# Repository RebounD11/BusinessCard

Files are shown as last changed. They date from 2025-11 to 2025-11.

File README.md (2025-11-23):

# Overview

This is a simple 4-layer PCB, the size of a credit card (approximately - 85.6 mm x 54 mm with rounded corners) that has the main purpose of being a business card and secondary purposes of not beoming e-waste once the novelty has worn off.  

# Functionality

## First impression 

When handing out the card, the front side will look like this:

## Power up

## Connecting

## Clearing connections

## Clock functionality

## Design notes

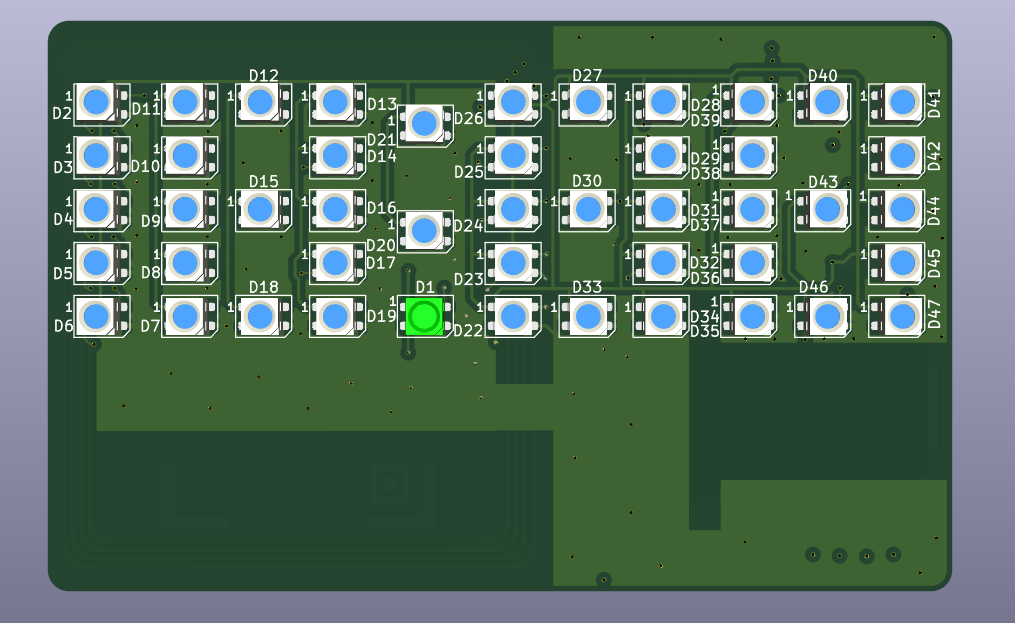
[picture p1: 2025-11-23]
Images/Config_PM_Indicator.png

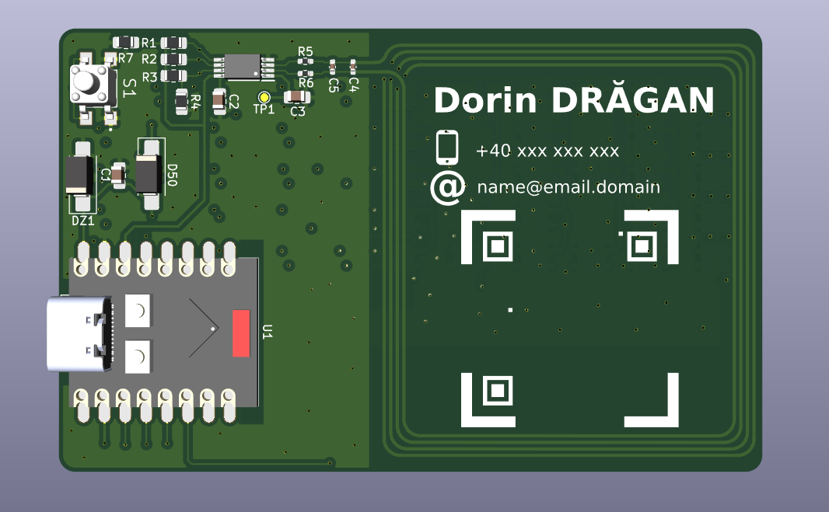
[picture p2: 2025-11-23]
Images/Front.png

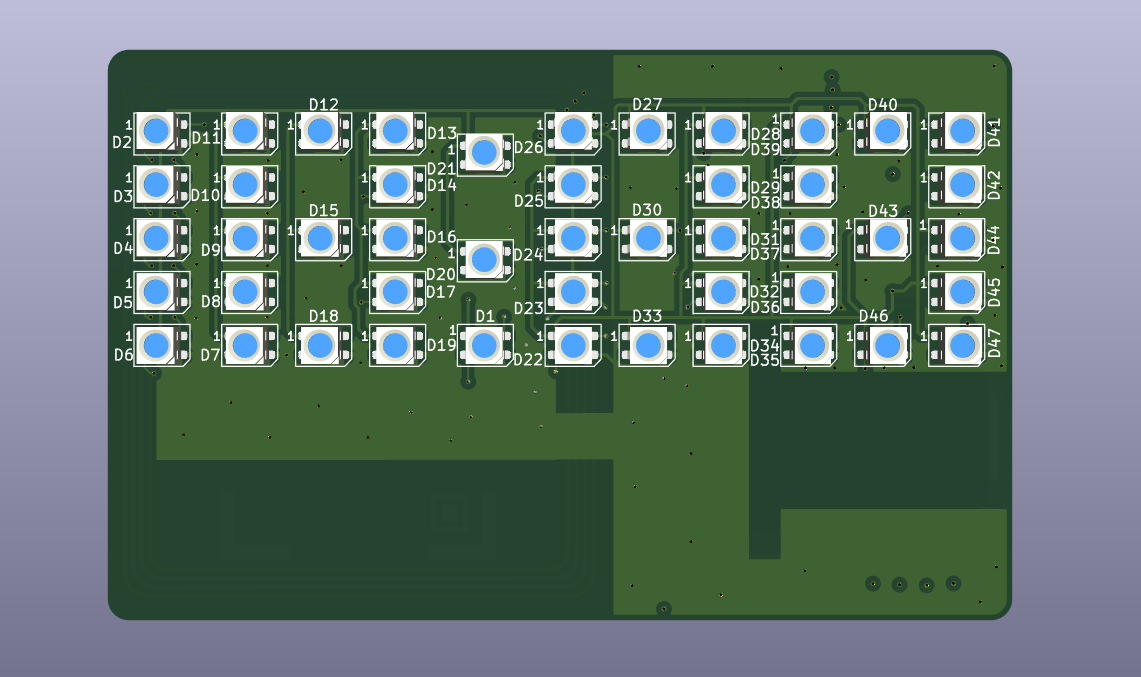
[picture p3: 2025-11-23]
Images/Clock.png

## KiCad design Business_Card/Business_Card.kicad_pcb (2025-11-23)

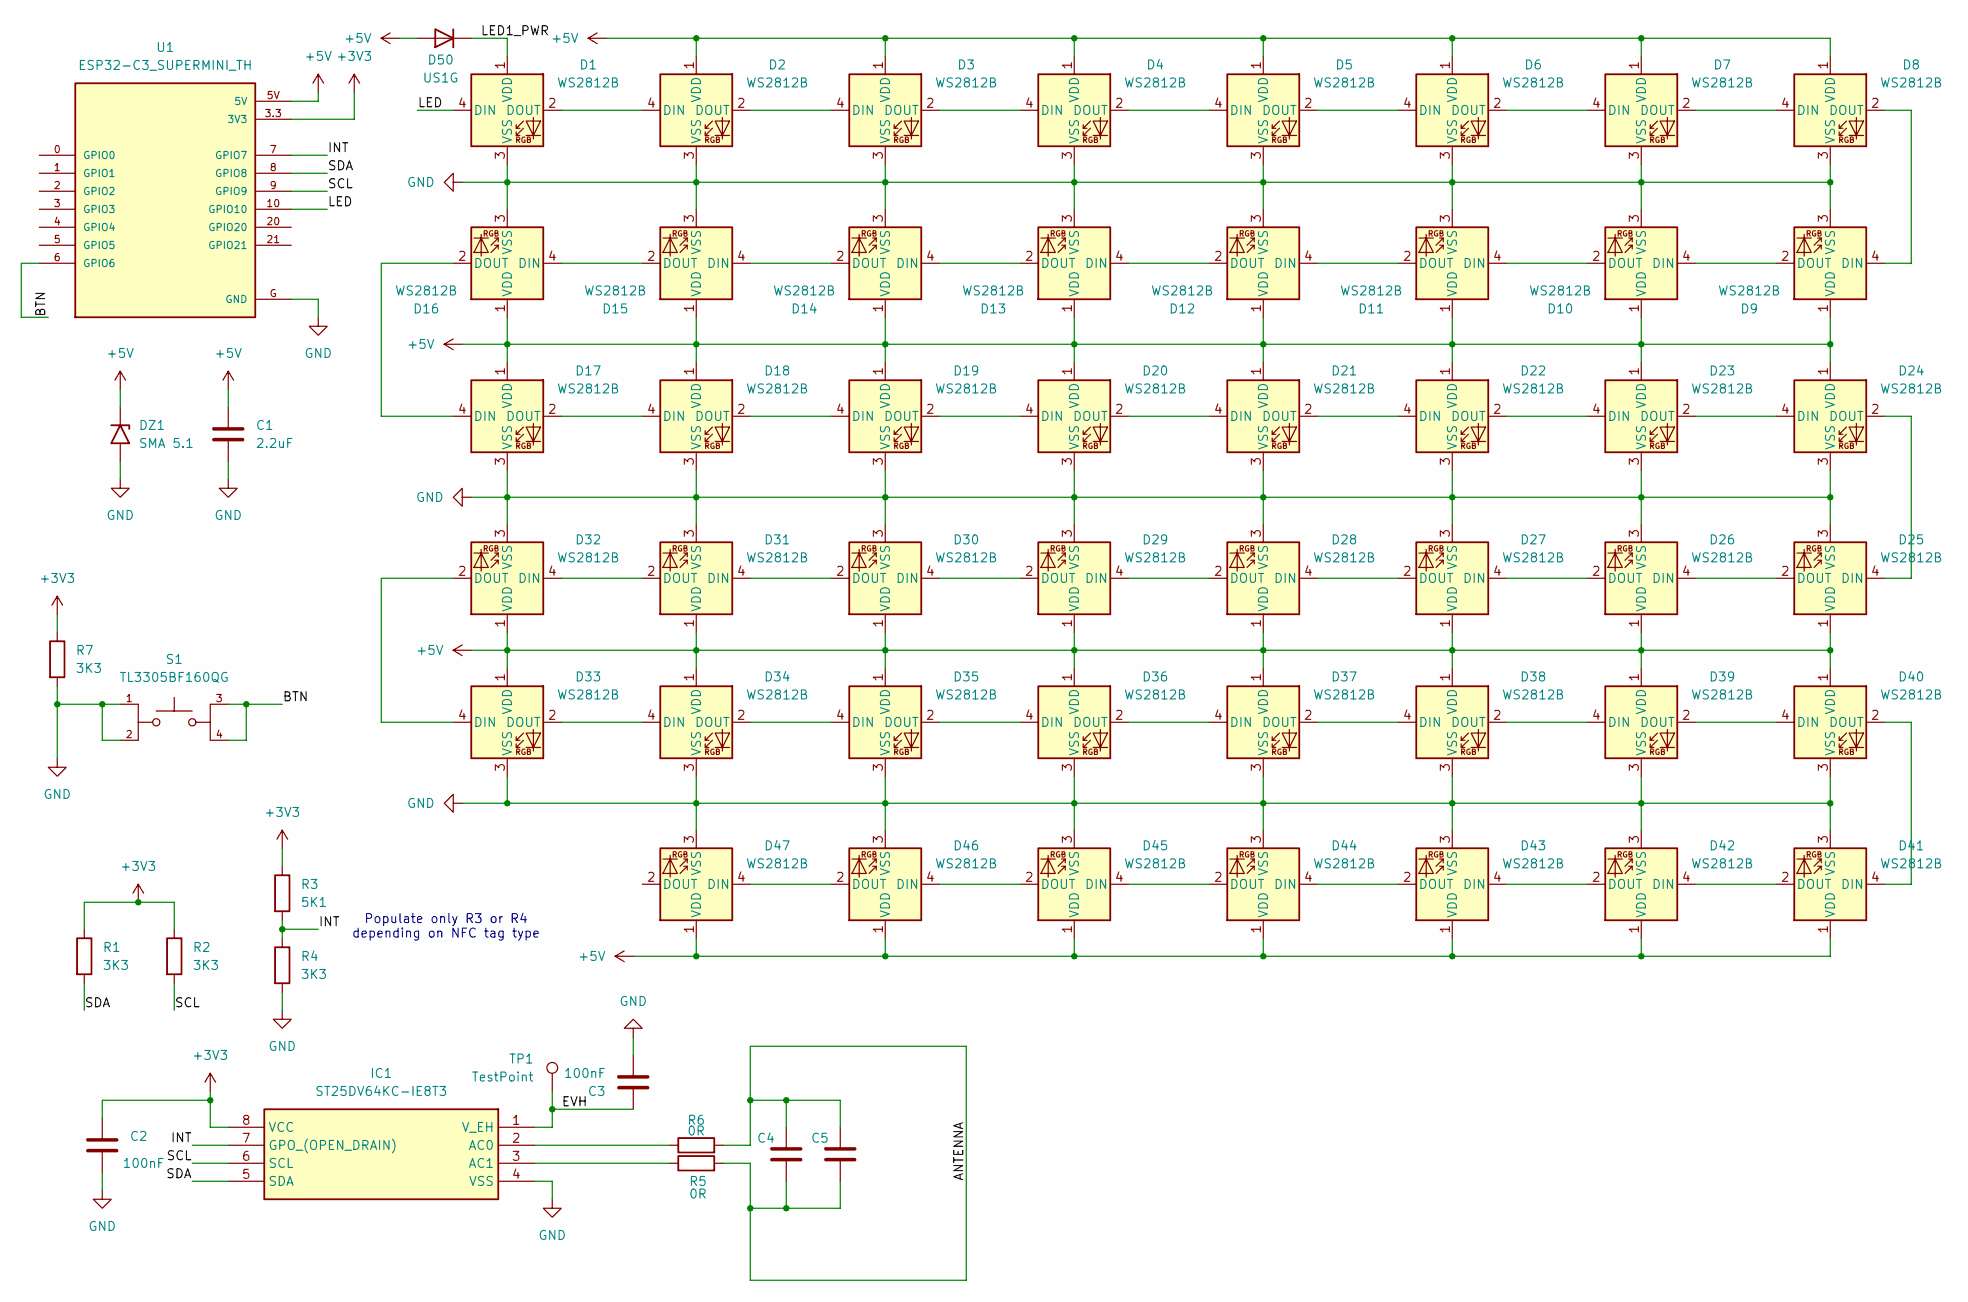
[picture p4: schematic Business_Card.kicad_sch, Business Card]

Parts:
C1: 2.2uF; C_0805_2012Metric_Pad1.18x1.45mm_HandSolder
C2, C3: 100nF; C_0805_2012Metric_Pad1.18x1.45mm_HandSolder
C4, C5: C_0402_1005Metric_Pad0.74x0.62mm_HandSolder
D1, D2, D3, D4, D5, D6, D7, D8, D9, D10, D11, D12, D13, D14, D15, D16, D17, D18, D19, D20, D21, D22, D23, D24, D25, D26, D27, D28, D29, D30, D31, D32, D33, D34, D35, D36, D37, D38, D39, D40, D41, D42, D43, D44, D45, D46, D47: WS2812B; LED_WS2812B-Mini_PLCC4_3.5x3.5mm
D50: US1G; D_SMA_Handsoldering
DZ1: SMA 5.1; D_SMA_Handsoldering
IC1: ST25DV64KC-IE8T3; SOP65P640X120-8N; Mouser Part Number 511-ST25DV64KC-IE8T3
R1, R2, R4, R7: 3K3; R_0805_2012Metric_Pad1.20x1.40mm_HandSolder
R3: 5K1; R_0805_2012Metric_Pad1.20x1.40mm_HandSolder
R5, R6: 0R; R_0402_1005Metric_Pad0.72x0.64mm_HandSolder
S1: TL3305BF160QG; SW_TL3305BF160QG; PARTREV C
TP1: TestPoint; TestPoint_Pad_D1.0mm
U1: ESP32-C3_SUPERMINI_TH; MODULE_ESP32-C3_SUPERMINI_TH

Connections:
+3V3: C2.1, IC1.8 (VCC), R1.1, R2.1, R3.1, R7.1, U1.3.3 (3V3)
+5V: C1.1, D2.1 (VDD), D3.1 (VDD), D4.1 (VDD), D5.1 (VDD), D6.1 (VDD), D7.1 (VDD), D8.1 (VDD), D9.1 (VDD), D10.1 (VDD), D11.1 (VDD), D12.1 (VDD), D13.1 (VDD), D14.1 (VDD), D15.1 (VDD), D16.1 (VDD), D17.1 (VDD), D18.1 (VDD), D19.1 (VDD), D20.1 (VDD), D21.1 (VDD), D22.1 (VDD), D23.1 (VDD), D24.1 (VDD), D25.1 (VDD), D26.1 (VDD), D27.1 (VDD), D28.1 (VDD), D29.1 (VDD), D30.1 (VDD), D31.1 (VDD), D32.1 (VDD), D33.1 (VDD), D34.1 (VDD), D35.1 (VDD), D36.1 (VDD), D37.1 (VDD), D38.1 (VDD), D39.1 (VDD), D40.1 (VDD), D41.1 (VDD), D42.1 (VDD), D43.1 (VDD), D44.1 (VDD), D45.1 (VDD), D46.1 (VDD), D47.1 (VDD), D50.2 (A), DZ1.1 (A1), U1.5V
/ANTENNA: C4.1, C4.2, C5.1, C5.2, R5.2, R6.2
/BTN: S1.3, S1.4, U1.6 (GPIO6)
/EVH: C3.1, IC1.1 (V_EH), TP1.1
/INT: IC1.7 (GPO_(OPEN_DRAIN)), R3.2, R4.1, U1.7 (GPIO7)
/LED: D1.4 (DIN), U1.10 (GPIO10)
/LED1_PWR: D1.1 (VDD), D50.1 (K)
/SCL: IC1.6 (SCL), R2.2, U1.9 (GPIO9)
/SDA: IC1.5 (SDA), R1.2, U1.8 (GPIO8)
GND: C1.2, C2.2, C3.2, D1.3 (VSS), D2.3 (VSS), D3.3 (VSS), D4.3 (VSS), D5.3 (VSS), D6.3 (VSS), D7.3 (VSS), D8.3 (VSS), D9.3 (VSS), D10.3 (VSS), D11.3 (VSS), D12.3 (VSS), D13.3 (VSS), D14.3 (VSS), D15.3 (VSS), D16.3 (VSS), D17.3 (VSS), D18.3 (VSS), D19.3 (VSS), D20.3 (VSS), D21.3 (VSS), D22.3 (VSS), D23.3 (VSS), D24.3 (VSS), D25.3 (VSS), D26.3 (VSS), D27.3 (VSS), D28.3 (VSS), D29.3 (VSS), D30.3 (VSS), D31.3 (VSS), D32.3 (VSS), D33.3 (VSS), D34.3 (VSS), D35.3 (VSS), D36.3 (VSS), D37.3 (VSS), D38.3 (VSS), D39.3 (VSS), D40.3 (VSS), D41.3 (VSS), D42.3 (VSS), D43.3 (VSS), D44.3 (VSS), D45.3 (VSS), D46.3 (VSS), D47.3 (VSS), DZ1.2 (A2), IC1.4 (VSS), R4.2, R7.2, S1.1, S1.2, U1.G (GND)
unnamed: D1.2 (DOUT), D2.4 (DIN)
unnamed: D2.2 (DOUT), D3.4 (DIN)
unnamed: D3.2 (DOUT), D4.4 (DIN)
unnamed: D4.2 (DOUT), D5.4 (DIN)
unnamed: D5.2 (DOUT), D6.4 (DIN)
unnamed: D6.2 (DOUT), D7.4 (DIN)
unnamed: D7.2 (DOUT), D8.4 (DIN)
unnamed: D8.2 (DOUT), D9.4 (DIN)
unnamed: D9.2 (DOUT), D10.4 (DIN)
unnamed: D10.2 (DOUT), D11.4 (DIN)
unnamed: D11.2 (DOUT), D12.4 (DIN)
unnamed: D12.2 (DOUT), D13.4 (DIN)
unnamed: D13.2 (DOUT), D14.4 (DIN)
unnamed: D14.2 (DOUT), D15.4 (DIN)
unnamed: D15.2 (DOUT), D16.4 (DIN)
unnamed: D16.2 (DOUT), D17.4 (DIN)
unnamed: D17.2 (DOUT), D18.4 (DIN)
unnamed: D18.2 (DOUT), D19.4 (DIN)
unnamed: D19.2 (DOUT), D20.4 (DIN)
unnamed: D20.2 (DOUT), D21.4 (DIN)
unnamed: D21.2 (DOUT), D22.4 (DIN)
unnamed: D22.2 (DOUT), D23.4 (DIN)
unnamed: D23.2 (DOUT), D24.4 (DIN)
unnamed: D24.2 (DOUT), D25.4 (DIN)
unnamed: D25.2 (DOUT), D26.4 (DIN)
unnamed: D26.2 (DOUT), D27.4 (DIN)
unnamed: D27.2 (DOUT), D28.4 (DIN)
unnamed: D28.2 (DOUT), D29.4 (DIN)
unnamed: D29.2 (DOUT), D30.4 (DIN)
unnamed: D30.2 (DOUT), D31.4 (DIN)
unnamed: D31.2 (DOUT), D32.4 (DIN)
unnamed: D32.2 (DOUT), D33.4 (DIN)
unnamed: D33.2 (DOUT), D34.4 (DIN)
unnamed: D34.2 (DOUT), D35.4 (DIN)
unnamed: D35.2 (DOUT), D36.4 (DIN)
unnamed: D36.2 (DOUT), D37.4 (DIN)
unnamed: D37.2 (DOUT), D38.4 (DIN)
unnamed: D38.2 (DOUT), D39.4 (DIN)
unnamed: D39.2 (DOUT), D40.4 (DIN)
unnamed: D40.2 (DOUT), D41.4 (DIN)
unnamed: D41.2 (DOUT), D42.4 (DIN)
unnamed: D42.2 (DOUT), D43.4 (DIN)
unnamed: D43.2 (DOUT), D44.4 (DIN)
unnamed: D44.2 (DOUT), D45.4 (DIN)
unnamed: D45.2 (DOUT), D46.4 (DIN)
unnamed: D46.2 (DOUT), D47.4 (DIN)
unnamed: IC1.2 (AC0), R6.1
unnamed: IC1.3 (AC1), R5.1

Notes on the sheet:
Populate only R3 or R4 depending on NFC tag type

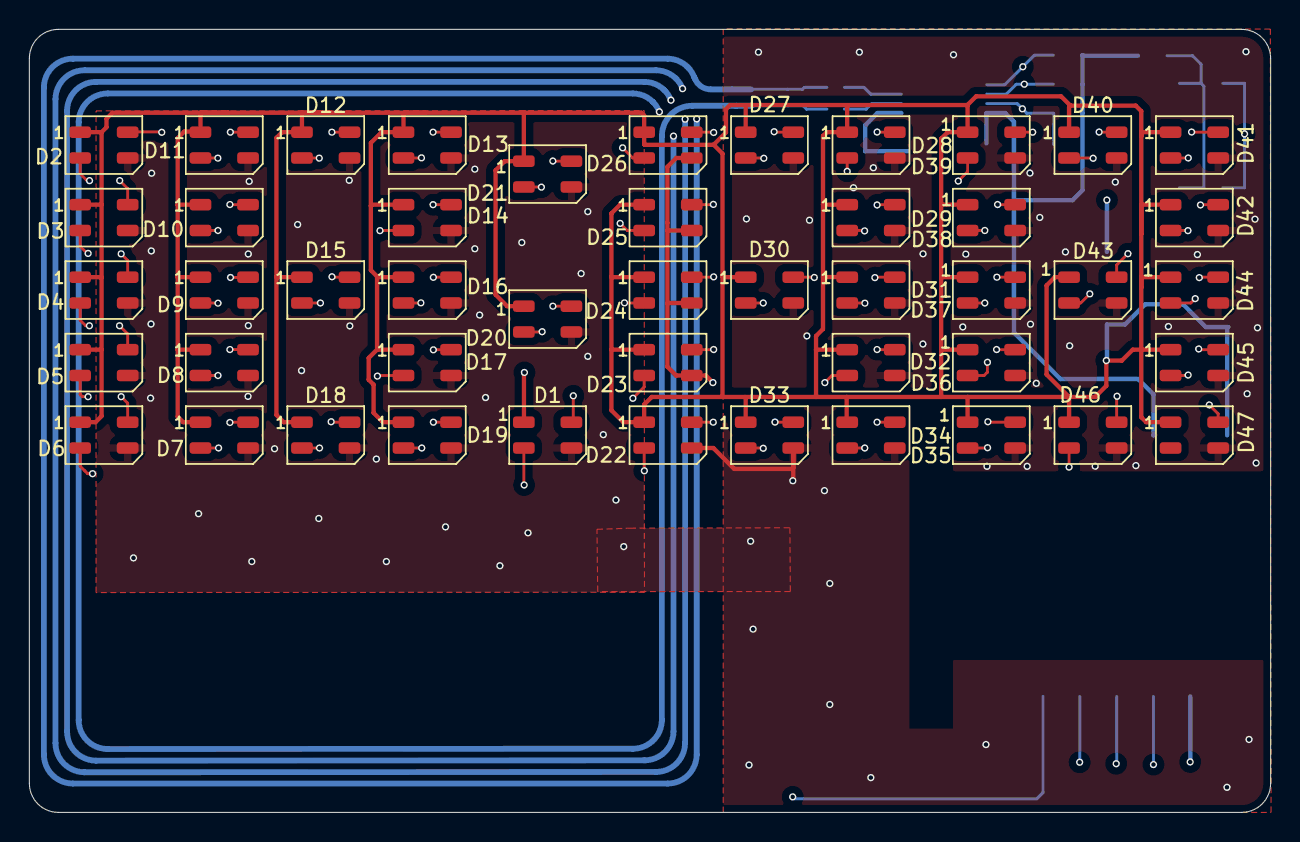
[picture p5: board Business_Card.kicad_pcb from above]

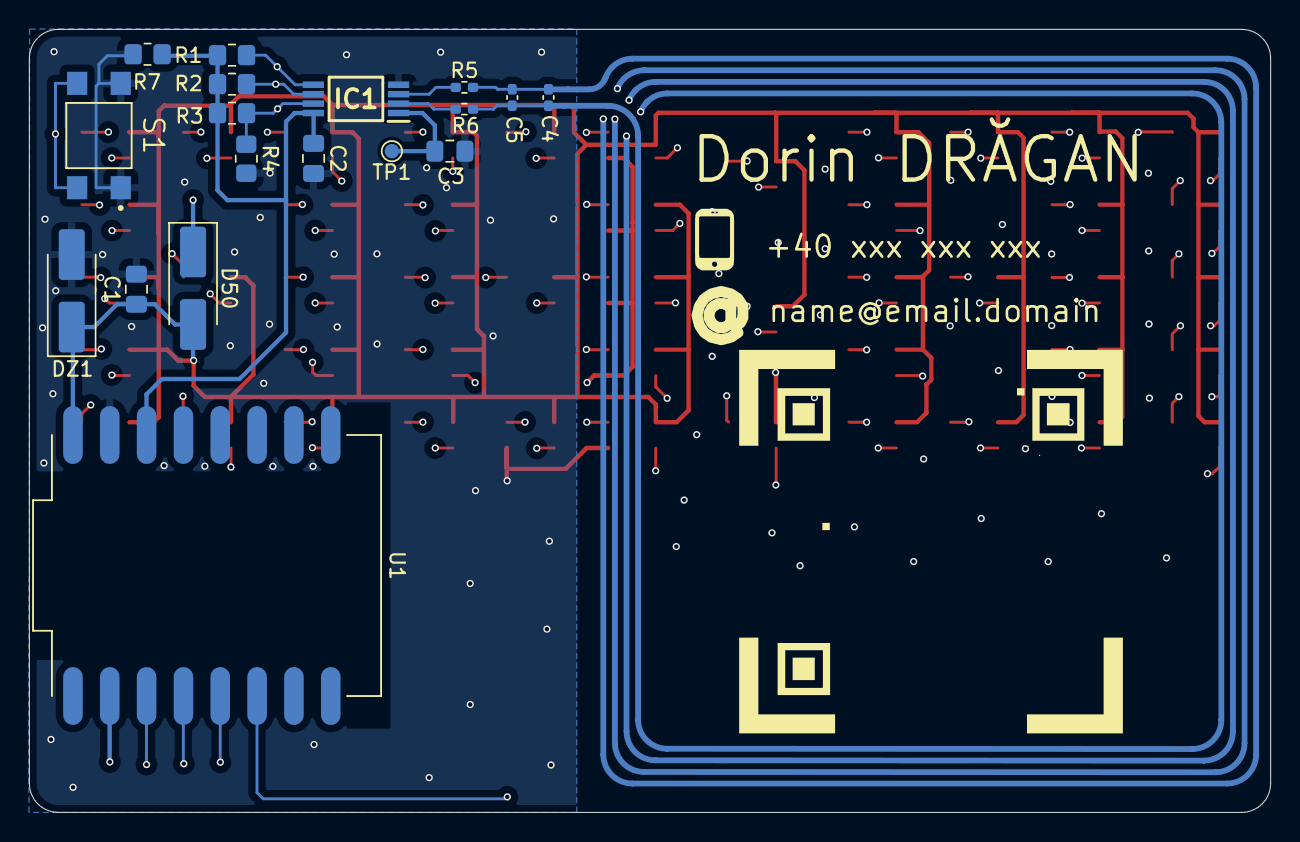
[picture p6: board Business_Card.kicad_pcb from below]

Board: 4 copper layers, 85.6 x 54.0 mm, 65 parts (18 on the bottom side), 59 nets.

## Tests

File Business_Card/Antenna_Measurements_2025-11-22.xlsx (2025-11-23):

 |  |  |  |  | R_A = R_SDC+R_SAC
 |  |  |  |  | L_A = L_A @1 MHz
 |  |  |  |  | C_A = 1/(L_A*(2πF_res)^2)
 |  |  |  |  |  |  |  |  | VNA
Markers [MHz] |  | L_A [µH] | R_SDC [Ω] | R_PAC [kΩ] | R_SAC [Ω] | Q | C_A [pF] | R_A [Ω] | L_A [nH] | C_A [pF] | R_A [Ω]
1 |  | 1.872 | 1.41 |  |  |  |  |  | 1872 | 31.63977235 | 4.440596464
13.56 |  | 3.117 |  | 8.393878766 | 3.030596464 | 35.91733402 |  | 4.440596464
F_res | 20.68 |  |  | 6.797 |  |  | 31.63977235

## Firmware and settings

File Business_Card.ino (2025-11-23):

// Business card
#include <Adafruit_NeoPixel.h>
#include <WiFiManager.h>
#include "time.h"

#define LED_PIN 10
#define BUTTON_PIN 6

#define LED_COUNT 47

Adafruit_NeoPixel strip(LED_COUNT, LED_PIN, NEO_GRB + NEO_KHZ800);
WiFiManager wm;

const char* ntpServer = "0.ro.pool.ntp.org";
const long  gmtOffset_sec = 7200;
int   daylightOffset_sec = 3600;
bool secOn = false;
volatile bool btnPush = false;
volatile int cntPush = 0;
//variables to keep track of the timing of recent interrupts
volatile unsigned long button_time = 0;
volatile unsigned long last_button_time = 0;

uint32_t color;
struct tm timeinfo;

void IRAM_ATTR buttonPressed() {
  button_time = millis();
  if (button_time - last_button_time > 250) {
    if (cntPush == 6) {
      cntPush = 0;
    }
    else {
      cntPush++;
    }
    btnPush = true;
    last_button_time = button_time;
  }
}

void setup() {
  // put your setup code here, to run once:
  // initialize strip
  strip.begin();           // INITIALIZE NeoPixel strip object (REQUIRED)
  strip.show();            // Turn OFF all pixels ASAP
  strip.setBrightness(50); // Set BRIGHTNESS to about 1/5 (max = 255)
  strip.setPixelColor(0, strip.Color(255,  127,  63));
  strip.show();
  // initialize button
  pinMode(BUTTON_PIN, INPUT_PULLUP);
  // initialize WiFi
  WiFi.mode(WIFI_STA); // explicitly set mode, esp defaults to STA+AP 
  // initalize WiFi Manager
  std::vector<const char *> menu = {"wifi","info","param","sep","restart","exit"};
  wm.setMenu(menu);
  wm.setClass("invert"); // dark mode
  wm.setConnectTimeout(120);
  wm.setConfigPortalTimeout(120);
  bool res;
  if (digitalRead(BUTTON_PIN) == LOW) {
    delay(3000);
    if (digitalRead(BUTTON_PIN) == LOW) {
      wm.resetSettings();
      ESP.restart();
    }
    wm.setConfigPortalTimeout(120);
    if (!wm.startConfigPortal("OnDemandAP","password")) {
      delay(3000);
      //ESP.restart();
    } else {
      //if you get here you have connected to the WiFi
      // get NTP time
      configTime(gmtOffset_sec, daylightOffset_sec, ntpServer);
    }
  }
  else {
    res = wm.autoConnect("AutoConnectAP","password");
    if (!res) {
      //ESP.restart();
    }
    else {
      //if you get here you have connected to the WiFi
      // get NTP time
      configTime(gmtOffset_sec, daylightOffset_sec, ntpServer);
    }
  }
  attachInterrupt(BUTTON_PIN, buttonPressed, FALLING);
}

void loop() {
  // put your main code here, to run repeatedly:
  // check if button was pressed
  if (btnPush) {
    // set color
    switch (cntPush) {
      case 0:
        color = strip.Color(127, 127, 127);
        break;
      case 1:
        color = strip.Color(127, 0, 0);
        break;
      case 2:
        color = strip.Color(0, 127, 0);
        break;
      case 3:
        color = strip.Color(0, 0, 127);
        break;
      case 4:
        color = strip.Color(127, 127, 0);
        break;
      case 5:
        color = strip.Color(127, 0, 127);
        break;
      case 6:
        color = strip.Color(0, 127, 127);
        break;
      default:
        //default to white
        color = strip.Color(127, 127, 127);
        break;
    }
    btnPush = false;
  }
  // actual app
  if(!getLocalTime(&timeinfo)){
    // failed to get time
  }
  else {
    // clear clock
    for (int i=0; i<LED_COUNT; i++) {
      strip.setPixelColor(i, strip.Color(0, 0, 0));
    }
    secOn = !secOn;
    // set PM indicator
    if (timeinfo.tm_hour >= 12) {
      strip.setPixelColor(0, color);
    }
    else {
      strip.setPixelColor(0, strip.Color(0, 0, 0));
    }
    // hour tens - 1 or none
    if ((timeinfo.tm_hour == 0) || (timeinfo.tm_hour == 10) || (timeinfo.tm_hour == 11) || (timeinfo.tm_hour == 12) || (timeinfo.tm_hour == 22) || (timeinfo.tm_hour == 23)) {
      for (int i=1; i<=5; i++) {
        strip.setPixelColor(i, color);
      }
    }
    else {
      for (int i=1; i<=5; i++) {
        strip.setPixelColor(i, strip.Color(0, 0, 0));
      }
    }
    // hour units - 0
    if ((timeinfo.tm_hour == 22) || (timeinfo.tm_hour == 10)) {
      strip.setPixelColor(6, color);
      strip.setPixelColor(7, color);
      strip.setPixelColor(8, color);
      strip.setPixelColor(9, color);
      strip.setPixelColor(10, color);
      strip.setPixelColor(11, color);
      strip.setPixelColor(12, color);
      strip.setPixelColor(13, color);
      strip.setPixelColor(15, color);
      strip.setPixelColor(16, color);
      strip.setPixelColor(17, color);
      strip.setPixelColor(18, color);
    }
    // hour units - 1
    else if ((timeinfo.tm_hour == 23) || (timeinfo.tm_hour == 11) || (timeinfo.tm_hour == 13) || (timeinfo.tm_hour == 1)) {
      strip.setPixelColor(12, color);
      strip.setPixelColor(13, color);
      strip.setPixelColor(15, color);
      strip.setPixelColor(16, color);
      strip.setPixelColor(18, color);
    }
    // hour units - 2
    else if ((timeinfo.tm_hour == 0) || (timeinfo.tm_hour == 12) || (timeinfo.tm_hour == 14) || (timeinfo.tm_hour == 2)) {
      strip.setPixelColor(6, color);
      strip.setPixelColor(7, color);
      strip.setPixelColor(8, color);
      strip.setPixelColor(10, color);
      strip.setPixelColor(11, color);
      strip.setPixelColor(12, color);
      strip.setPixelColor(13, color);
      strip.setPixelColor(14, color);
      strip.setPixelColor(15, color);
      strip.setPixelColor(17, color);
      strip.setPixelColor(18, color);
    }
    // hour units - 3
    else if ((timeinfo.tm_hour == 3) || (timeinfo.tm_hour == 15)) {
      strip.setPixelColor(6, color);
      strip.setPixelColor(8, color);
      strip.setPixelColor(10, color);
      strip.setPixelColor(11, color);
      strip.setPixelColor(12, color);
      strip.setPixelColor(13, color);
      strip.setPixelColor(14, color);
      strip.setPixelColor(15, color);
      strip.setPixelColor(16, color);
      strip.setPixelColor(17, color);
      strip.setPixelColor(18, color);
    }
    // hour units - 4
    else if ((timeinfo.tm_hour == 4) || (timeinfo.tm_hour == 16)) {
      strip.setPixelColor(8, color);
      strip.setPixelColor(9, color);
      strip.setPixelColor(10, color);
      strip.setPixelColor(12, color);
      strip.setPixelColor(13, color);
      strip.setPixelColor(14, color);
      strip.setPixelColor(15, color);
      strip.setPixelColor(16, color);
      strip.setPixelColor(18, color);
    }
    // hour units - 5
    else if ((timeinfo.tm_hour == 5) || (timeinfo.tm_hour == 17)) {
      strip.setPixelColor(6, color);
      strip.setPixelColor(8, color);
      strip.setPixelColor(9, color);
      strip.setPixelColor(10, color);
      strip.setPixelColor(11, color);
      strip.setPixelColor(12, color);
      strip.setPixelColor(14, color);
      strip.setPixelColor(15, color);
      strip.setPixelColor(16, color);
      strip.setPixelColor(17, color);
      strip.setPixelColor(18, color);
    }
    // hour units - 6
    else if ((timeinfo.tm_hour == 6) || (timeinfo.tm_hour == 18)) {
      strip.setPixelColor(6, color);
      strip.setPixelColor(7, color);
      strip.setPixelColor(8, color);
      strip.setPixelColor(9, color);
      strip.setPixelColor(10, color);
      strip.setPixelColor(11, color);
      strip.setPixelColor(12, color);
      strip.setPixelColor(14, color);
      strip.setPixelColor(15, color);
      strip.setPixelColor(16, color);
      strip.setPixelColor(17, color);
      strip.setPixelColor(18, color);
    }
    // hour units - 7
    else if ((timeinfo.tm_hour == 7) || (timeinfo.tm_hour == 19)) {
      strip.setPixelColor(10, color);
      strip.setPixelColor(11, color);
      strip.setPixelColor(12, color);
      strip.setPixelColor(13, color);
      strip.setPixelColor(15, color);
      strip.setPixelColor(16, color);
      strip.setPixelColor(18, color);
    }
    // hour units - 8
    else if ((timeinfo.tm_hour == 8) || (timeinfo.tm_hour == 20)) {
      strip.setPixelColor(6, color);
      strip.setPixelColor(7, color);
      strip.setPixelColor(8, color);
      strip.setPixelColor(9, color);
      strip.setPixelColor(10, color);
      strip.setPixelColor(11, color);
      strip.setPixelColor(12, color);
      strip.setPixelColor(13, color);
      strip.setPixelColor(14, color);
      strip.setPixelColor(15, color);
      strip.setPixelColor(16, color);
      strip.setPixelColor(17, color);
      strip.setPixelColor(18, color);
    }
    // hour units - 9
    else if ((timeinfo.tm_hour == 9) || (timeinfo.tm_hour == 21)) {
      strip.setPixelColor(6, color);
      strip.setPixelColor(8, color);
      strip.setPixelColor(9, color);
      strip.setPixelColor(10, color);
      strip.setPixelColor(11, color);
      strip.setPixelColor(12, color);
      strip.setPixelColor(13, color);
      strip.setPixelColor(14, color);
      strip.setPixelColor(15, color);
      strip.setPixelColor(16, color);
      strip.setPixelColor(17, color);
      strip.setPixelColor(18, color);
    }
    if (secOn) {
      strip.setPixelColor(19, color);
      strip.setPixelColor(20, color);
    }
    else {
      strip.setPixelColor(19, strip.Color(0, 0, 0));
      strip.setPixelColor(20, strip.Color(0, 0, 0));
    }
    // min tens is 0
    if (timeinfo.tm_min < 10) {
      strip.setPixelColor(21, color);
      strip.setPixelColor(22, color);
      strip.setPixelColor(23, color);
      strip.setPixelColor(24, color);
      strip.setPixelColor(25, color);
      strip.setPixelColor(26, color);
      strip.setPixelColor(27, color);
      strip.setPixelColor(28, color);
      strip.setPixelColor(30, color);
      strip.setPixelColor(31, color);
      strip.setPixelColor(32, color);
      strip.setPixelColor(33, color);
    }
    // min tens is 1
    else if ((timeinfo.tm_min >= 10) && (timeinfo.tm_min < 20)) {
      strip.setPixelColor(27, color);
      strip.setPixelColor(28, color);
      strip.setPixelColor(30, color);
      strip.setPixelColor(31, color);
      strip.setPixelColor(33, color);
    }
    // min tens is 2
    else if ((timeinfo.tm_min >= 20) && (timeinfo.tm_min < 30)) {
      strip.setPixelColor(21, color);
      strip.setPixelColor(22, color);
      strip.setPixelColor(23, color);
      strip.setPixelColor(25, color);
      strip.setPixelColor(26, color);
      strip.setPixelColor(27, color);
      strip.setPixelColor(28, color);
      strip.setPixelColor(29, color);
      strip.setPixelColor(30, color);
      strip.setPixelColor(32, color);
      strip.setPixelColor(33, color);
    }
    // min tens is 3
    else if ((timeinfo.tm_min >= 30) && (timeinfo.tm_min < 40)) {
      strip.setPixelColor(21, color);
      strip.setPixelColor(23, color);
      strip.setPixelColor(25, color);
      strip.setPixelColor(26, color);
      strip.setPixelColor(27, color);
      strip.setPixelColor(28, color);
      strip.setPixelColor(29, color);
      strip.setPixelColor(30, color);
      strip.setPixelColor(31, color);
      strip.setPixelColor(32, color);
      strip.setPixelColor(33, color);
    }
    // min tens is 4
    else if ((timeinfo.tm_min >= 40) && (timeinfo.tm_min < 50)) {
      strip.setPixelColor(23, color);
      strip.setPixelColor(24, color);
      strip.setPixelColor(25, color);
      strip.setPixelColor(27, color);
      strip.setPixelColor(28, color);
      strip.setPixelColor(29, color);
      strip.setPixelColor(30, color);
      strip.setPixelColor(31, color);
      strip.setPixelColor(33, color);
    }
    // min tens is 5
    else if ((timeinfo.tm_min >= 50) && (timeinfo.tm_min < 60)) {
      strip.setPixelColor(21, color);
      strip.setPixelColor(23, color);
      strip.setPixelColor(24, color);
      strip.setPixelColor(25, color);
      strip.setPixelColor(26, color);
      strip.setPixelColor(27, color);
      strip.setPixelColor(29, color);
      strip.setPixelColor(30, color);
      strip.setPixelColor(31, color);
      strip.setPixelColor(32, color);
      strip.setPixelColor(33, color);
    }
    // min units is 0
    if ((timeinfo.tm_min == 0) || (timeinfo.tm_min == 10) || (timeinfo.tm_min == 20) || (timeinfo.tm_min == 30) || (timeinfo.tm_min == 40) || (timeinfo.tm_min == 50)) {
      strip.setPixelColor(34, color);
      strip.setPixelColor(35, color);
      strip.setPixelColor(36, color);
      strip.setPixelColor(37, color);
      strip.setPixelColor(38, color);
      strip.setPixelColor(39, color);
      strip.setPixelColor(40, color);
      strip.setPixelColor(41, color);
      strip.setPixelColor(43, color);
      strip.setPixelColor(44, color);
      strip.setPixelColor(45, color);
      strip.setPixelColor(46, color);
    }
    // min units is 1
    else if ((timeinfo.tm_min == 1) || (timeinfo.tm_min == 11) || (timeinfo.tm_min == 21) || (timeinfo.tm_min == 31) || (timeinfo.tm_min == 41) || (timeinfo.tm_min == 51)) {
      strip.setPixelColor(40, color);
      strip.setPixelColor(41, color);
      strip.setPixelColor(43, color);
      strip.setPixelColor(44, color);
      strip.setPixelColor(46, color);
    }
    // min units is 2
    else if ((timeinfo.tm_min == 2) || (timeinfo.tm_min == 12) || (timeinfo.tm_min == 22) || (timeinfo.tm_min == 32) || (timeinfo.tm_min == 42) || (timeinfo.tm_min == 52)) {
      strip.setPixelColor(34, color);
      strip.setPixelColor(35, color);
      strip.setPixelColor(36, color);
      strip.setPixelColor(38, color);
      strip.setPixelColor(39, color);
      strip.setPixelColor(40, color);
      strip.setPixelColor(41, color);
      strip.setPixelColor(42, color);
      strip.setPixelColor(43, color);
      strip.setPixelColor(45, color);
      strip.setPixelColor(46, color);
    }
    // min units is 3
    else if ((timeinfo.tm_min == 3) || (timeinfo.tm_min == 13) || (timeinfo.tm_min == 23) || (timeinfo.tm_min == 33) || (timeinfo.tm_min == 43) || (timeinfo.tm_min == 53)) {
      strip.setPixelColor(34, color);
      strip.setPixelColor(36, color);
      strip.setPixelColor(38, color);
      strip.setPixelColor(39, color);
      strip.setPixelColor(40, color);
      strip.setPixelColor(41, color);
      strip.setPixelColor(42, color);
      strip.setPixelColor(43, color);
      strip.setPixelColor(44, color);
      strip.setPixelColor(45, color);
      strip.setPixelColor(46, color);
    }
    // min units is 4
    else if ((timeinfo.tm_min == 4) || (timeinfo.tm_min == 14) || (timeinfo.tm_min == 24) || (timeinfo.tm_min == 34) || (timeinfo.tm_min == 44) || (timeinfo.tm_min == 54)) {
      strip.setPixelColor(36, color);
      strip.setPixelColor(37, color);
      strip.setPixelColor(38, color);
      strip.setPixelColor(40, color);
      strip.setPixelColor(41, color);
      strip.setPixelColor(42, color);
      strip.setPixelColor(43, color);
      strip.setPixelColor(44, color);
      strip.setPixelColor(46, color);
    }
    // min units is 5
    else if ((timeinfo.tm_min == 5) || (timeinfo.tm_min == 15) || (timeinfo.tm_min == 25) || (timeinfo.tm_min == 35) || (timeinfo.tm_min == 45) || (timeinfo.tm_min == 55)) {
      strip.setPixelColor(34, color);
      strip.setPixelColor(36, color);
      strip.setPixelColor(37, color);
      strip.setPixelColor(38, color);
      strip.setPixelColor(39, color);
      strip.setPixelColor(40, color);
      strip.setPixelColor(42, color);
      strip.setPixelColor(43, color);
      strip.setPixelColor(44, color);
      strip.setPixelColor(45, color);
      strip.setPixelColor(46, color);
    }
    // min units is 6
    else if ((timeinfo.tm_min == 6) || (timeinfo.tm_min == 16) || (timeinfo.tm_min == 26) || (timeinfo.tm_min == 36) || (timeinfo.tm_min == 46) || (timeinfo.tm_min == 56)) {
      strip.setPixelColor(34, color);
      strip.setPixelColor(35, color);
      strip.setPixelColor(36, color);
      strip.setPixelColor(37, color);
      strip.setPixelColor(38, color);
      strip.setPixelColor(39, color);
      strip.setPixelColor(40, color);
      strip.setPixelColor(42, color);
      strip.setPixelColor(43, color);
      strip.setPixelColor(44, color);
      strip.setPixelColor(45, color);
      strip.setPixelColor(46, color);
    }
    // min units is 7
    else if ((timeinfo.tm_min == 7) || (timeinfo.tm_min == 17) || (timeinfo.tm_min == 27) || (timeinfo.tm_min == 37) || (timeinfo.tm_min == 47) || (timeinfo.tm_min == 57)) {
      strip.setPixelColor(38, color);
      strip.setPixelColor(39, color);
      strip.setPixelColor(40, color);
      strip.setPixelColor(41, color);
      strip.setPixelColor(43, color);
      strip.setPixelColor(44, color);
      strip.setPixelColor(46, color);
    }
    // min units is 8
    else if ((timeinfo.tm_min == 8) || (timeinfo.tm_min == 18) || (timeinfo.tm_min == 28) || (timeinfo.tm_min == 38) || (timeinfo.tm_min == 48) || (timeinfo.tm_min == 58)) {
      strip.setPixelColor(34, color);
      strip.setPixelColor(35, color);
      strip.setPixelColor(36, color);
      strip.setPixelColor(37, color);
      strip.setPixelColor(38, color);
      strip.setPixelColor(39, color);
      strip.setPixelColor(40, color);
      strip.setPixelColor(41, color);
      strip.setPixelColor(42, color);
      strip.setPixelColor(43, color);
      strip.setPixelColor(44, color);
      strip.setPixelColor(45, color);
      strip.setPixelColor(46, color);
    }
    // min units is 9
    else if ((timeinfo.tm_min == 9) || (timeinfo.tm_min == 19) || (timeinfo.tm_min == 29) || (timeinfo.tm_min == 39) || (timeinfo.tm_min == 49) || (timeinfo.tm_min == 59)) {
      strip.setPixelColor(34, color);
      strip.setPixelColor(36, color);
      strip.setPixelColor(37, color);
      strip.setPixelColor(38, color);
      strip.setPixelColor(39, color);
      strip.setPixelColor(40, color);
      strip.setPixelColor(41, color);
      strip.setPixelColor(42, color);
      strip.setPixelColor(43, color);
      strip.setPixelColor(44, color);
      strip.setPixelColor(45, color);
      strip.setPixelColor(46, color);
    }
    strip.show();
  }
  delay(1000);
}

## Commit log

2025-11-23 Arduino Sketch
    Bad Arduino code to use with ESP32-C3 SuperMini
2025-11-23 KiCAD files
    Project, Schematic, Layout, Step, Gerbers
    [Business_Card-B_Cu.gbr, Business_Card-B_Mask.gbr, Business_Card-B_Paste.gbr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]
2025-11-23 Code outside KiCAD folder
    Moved outside of folder
2025-11-23 Delete Business_Card/Business_Card.kicad_pro
    Wrong version
2025-11-23 Delete Business_Card/Business_Card.kicad_sch
    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
    [Business_Card.kicad_sch]
2025-11-23 Correct versions
    Added measurements for NFC antenna
    [Antenna_Measurements_2025-11-22.xlsx, Business_Card.kicad_sch]
2025-11-23 More useful images
    Images of the PCB
